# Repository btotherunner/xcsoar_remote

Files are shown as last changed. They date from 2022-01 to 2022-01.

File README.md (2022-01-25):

# xcsoar_remote
XCSoar USB RemoteControl
<br>
<br>
XCSoar Remotecontroll / Fernbedieung
<br>
#### Hardware ####
1x ALPS SKQU 4 direction Joystick w/ Switch ~ 2,73 Euro <a href="https://www.exp-tech.de/zubehoer/tasterschalter/4727/alps-skqu-4-direction-joystick-w/switch">Link zu EXPTECH</a><br>
2x Tactile Button switch (6mm) ~ 3,15 Euro (20 Stück) <a href="https://www.exp-tech.de/zubehoer/tasterschalter/6974/tactile-button-switch-6mm-x-20-pack">Link zu EXPTECH</a><br>
1x Leiterplatte ~ 30 Euro (40 Stück)  <a href="https://www.pcbway.com/">PCB Prototype the Easy Way</a><br>
1x Arduino Leonardo Board ~ (3 Stück) 25,99 Euro <a href="https://www.amazon.de/gp/product/B07FQBQ4Z6/ref=ppx_yo_dt_b_search_asin_title?ie=UTF8&psc=1">Arduino Leonardo Board</a>

<br>
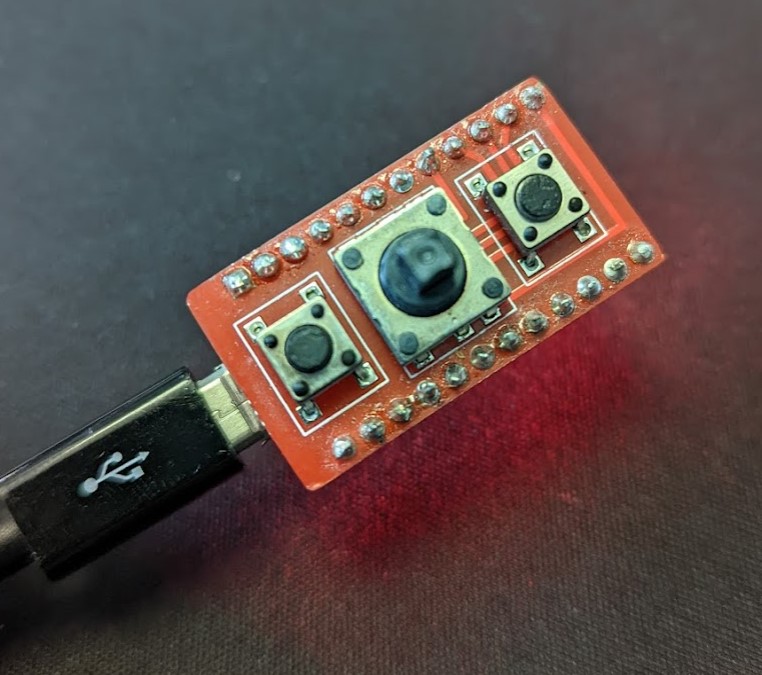
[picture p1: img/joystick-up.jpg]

<br>
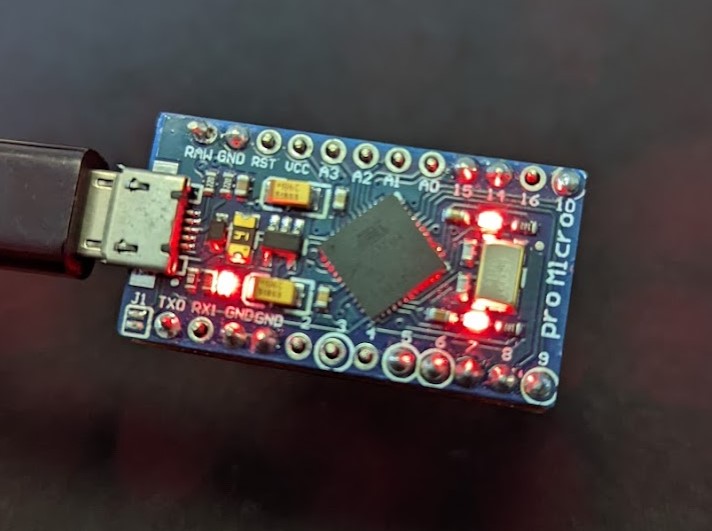
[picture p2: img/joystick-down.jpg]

<br>
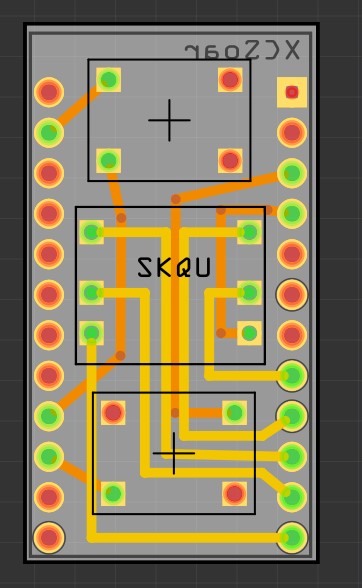
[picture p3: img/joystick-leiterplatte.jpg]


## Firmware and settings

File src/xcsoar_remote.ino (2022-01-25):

#include <Mouse.h>
#include <Keyboard.h>
#include <Button.h>
#include <ButtonEventCallback.h>
#include <PushButton.h>
#include <Bounce2.h>

// define on which pins the buttons are connected

//        Button_1_pin = N/A   // PTT switch
const int Button_2_pin = 15;    // upper LH button
const int Button_3_pin = 12;    // top button
const int Button_4_pin = 11;   // upper RH button
const int Button_5_pin = 14;   // lower RH button
const int Joy_button_pin = 6; // joystick button
const int Joy_up_pin = 9;
const int Joy_down_pin = 7;
const int Joy_left_pin = 5;
const int Joy_right_pin = 8;
const int STF_switch_pin = 4;  // STF switch 

// define press (short press) and hold (long press) functions for each button
// settings in XCSoar default.xci are
// F1 QuickMenu
// F2 Analysis
// F3 Checklist
// F4 FlarmTraffic
// F5 GotoLookup (Select Waypoint)
// F6 Setup Alternates
// F7 Setup Task
// F8 Setup Basic (wingload,bugs, QNH)
// F9
//    Status all
//    Calculator (tasks)
//
// settings in openvario.xci
// V for vario mode
// S for speed to fly mode
// M for vario menu
// Q to quit


//         Button_1 = N/A                         // PTT switch
const char Button_2_press_key = KEY_F1;           // F1 for QuickMenu
const char Button_2_hold_key = 'M';               // M for vario menu
const char Button_3_press_key = KEY_F3;           // F3 for checklist
const char Button_3_hold_key = KEY_F2;            // F2 for analysis
const char Button_4_press_key = KEY_F6;           // F6 for alternates
const char Button_4_hold_key = KEY_F5;            // F5 for waypoints
const char Button_5_press_key = KEY_ESC;          // ESC
const char Button_5_hold_key = 'Q';               // Q to quit XCSoar
const char Joy_button_press_key = KEY_RETURN;     // Enter
//         Joy_button_hold_key                    // switches between keyboard and mouse mode
const char STF_switch_on_key = 'V';               // V for vario mode when switch is on
const char STF_switch_off_key = 'S';              // S for STF mode when switch is off

// define timing for buttons etc.
const int Mouse_Move_Distance = 3;
const int joy_rebounce_interval = 3;
const int joy_key_rebounce_threshold = 20;
const int joy_key_first_pressed_threshold = 100;
const int button_hold_threshold = 500;
const int joy_hold_threshold = 1;
//const int debounce_delay = 10;                   //Debounce delay in milliseconds, not used

// define variables
boolean mouse_active = 0;
boolean first_pressed = 1;
int joy_key_counter = 0;


// Create instances of PushButtons on digital pins
PushButton STF_switch = PushButton(STF_switch_pin, ENABLE_INTERNAL_PULLUP);
PushButton Joy_up = PushButton(Joy_up_pin, ENABLE_INTERNAL_PULLUP);
PushButton Joy_down = PushButton(Joy_down_pin, ENABLE_INTERNAL_PULLUP);
PushButton Joy_left = PushButton(Joy_left_pin, ENABLE_INTERNAL_PULLUP);
PushButton Joy_right = PushButton(Joy_right_pin, ENABLE_INTERNAL_PULLUP);
PushButton Button_2 = PushButton(Button_2_pin, ENABLE_INTERNAL_PULLUP);
PushButton Button_3 = PushButton(Button_3_pin, ENABLE_INTERNAL_PULLUP);
PushButton Button_4 = PushButton(Button_4_pin, ENABLE_INTERNAL_PULLUP);
PushButton Button_5 = PushButton(Button_5_pin, ENABLE_INTERNAL_PULLUP);
PushButton Joy_button = PushButton(Joy_button_pin, ENABLE_INTERNAL_PULLUP);


void setup() {
  STF_switch.onPress(onSTF_switch);
  STF_switch.onRelease(onSTF_switch);
  
  Joy_up.onRelease(onJoyRelease);
  Joy_down.onRelease(onJoyRelease);
  Joy_left.onRelease(onJoyRelease);
  Joy_right.onRelease(onJoyRelease);

  Joy_up.onHoldRepeat(joy_hold_threshold, joy_rebounce_interval, onJoy);
  Joy_down.onHoldRepeat(joy_hold_threshold, joy_rebounce_interval, onJoy);
  Joy_left.onHoldRepeat(joy_hold_threshold, joy_rebounce_interval, onJoy);
  Joy_right.onHoldRepeat(joy_hold_threshold, joy_rebounce_interval, onJoy);
  
  Button_2.onRelease(0,button_hold_threshold-1,onButtonReleased);
  Button_3.onRelease(0,button_hold_threshold-1,onButtonReleased);
  Button_4.onRelease(0,button_hold_threshold-1,onButtonReleased);
  Button_5.onRelease(0,button_hold_threshold-1,onButtonReleased);
  Joy_button.onRelease(0,button_hold_threshold-1,onButtonReleased);
  
  Button_2.onHold(button_hold_threshold,onButtonHeld);
  Button_3.onHold(button_hold_threshold,onButtonHeld);
  Button_4.onHold(button_hold_threshold,onButtonHeld);
  Button_5.onHold(button_hold_threshold,onButtonHeld);
  Joy_button.onHold(button_hold_threshold,onButtonHeld);
 
  Keyboard.begin();
  Mouse.begin();
  joy_key_counter = 0;
}

void loop() {
  STF_switch.update();
  Button_2.update();
  Button_3.update();
  Button_4.update();
  Button_5.update();
  Joy_button.update();
  Joy_up.update();
  Joy_down.update();
  Joy_left.update();
  Joy_right.update();
}

void onButtonReleased(Button& btn){
  if(btn.is(Button_2)) Keyboard.press(Button_2_press_key);
  if(btn.is(Button_3)) Keyboard.press(Button_3_press_key);
  if(btn.is(Button_4)) Keyboard.press(Button_4_press_key);
  if(btn.is(Button_5)) Keyboard.press(Button_5_press_key);
  if(btn.is(Joy_button)) 
    if(mouse_active) Mouse.click(MOUSE_LEFT);
    else Keyboard.press(Joy_button_press_key);
  Keyboard.releaseAll();
}

void onButtonHeld(Button& btn){
  if(btn.is(Button_2)) Keyboard.press(Button_2_hold_key);
  if(btn.is(Button_3)) Keyboard.press(Button_3_hold_key);
  if(btn.is(Button_4)) Keyboard.press(Button_4_hold_key);
  if(btn.is(Button_5)) Keyboard.press(Button_5_hold_key);
  if(btn.is(Joy_button)) mouse_active = !mouse_active;
  Keyboard.releaseAll();  
} 


void onJoy(Button& btn){
  if(mouse_active && btn.isPressed()) {
    if(btn.is(Joy_up)) Mouse.move(0, -Mouse_Move_Distance);
    if(btn.is(Joy_down)) Mouse.move(0, Mouse_Move_Distance);
    if(btn.is(Joy_left)) Mouse.move(-Mouse_Move_Distance, 0);
    if(btn.is(Joy_right)) Mouse.move(Mouse_Move_Distance, 0);
  }
  if(!mouse_active && btn.isPressed() && joy_key_counter == 5) {
    if(btn.is(Joy_up)) Keyboard.press(KEY_UP_ARROW);
    if(btn.is(Joy_down)) Keyboard.press(KEY_DOWN_ARROW);
    if(btn.is(Joy_left)) Keyboard.press(KEY_LEFT_ARROW);
    if(btn.is(Joy_right)) Keyboard.press(KEY_RIGHT_ARROW);
    Keyboard.releaseAll(); 
  } 
  joy_key_counter = joy_key_counter +1; 
  if (first_pressed && joy_key_counter > joy_key_first_pressed_threshold){
    joy_key_counter = 0;
    first_pressed = 0;
  }
  if (!first_pressed && joy_key_counter > joy_key_rebounce_threshold)joy_key_counter = 0;  
}

void onJoyRelease(Button& btn){
  joy_key_counter = 0;
  first_pressed = 1;
}

void onSTF_switch(Button& btn){
  if(STF_switch.isPressed()) Keyboard.press(STF_switch_on_key);
  else
  Keyboard.press(STF_switch_off_key);
  Keyboard.releaseAll(); 
}

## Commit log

2021-06-14 Add frizing-files
    [xcsoar_remote.fzz]
2021-06-14 Add Images Case
2021-06-14 Upload 3D Case and Fusion Files
    [XCSoar_Remote v1.f3d, xcsoar_case_body.stl, xcsoar_case_deckel.stl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]
2021-06-14 Change Button Description
2021-06-14 Update Fritzing
    [xcsoar_remote.fzz]
2021-06-22 Add Button5
2021-06-25 Update FritzingFIle für Joystick
    [xcsoar_remote_joystick.fzz]
2021-06-25 Schema Anschluss - Joystick
    [xcsoar_remote_joystick.fzz]
2021-06-25 SKQU Anpassung
    [xcsoar_remote_joystick.fzz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]
2021-06-25 Update GerberFiles
    [xcsoar_remote_joystick.fzz]
2022-01-25 New Joystick Version
    [XCSoar_Remote v1.f3d, xcsoar_case_body.stl, xcsoar_case_deckel.stl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]
2022-01-25 Add Joystick Fritzing Leiterplatte
    [xcsoar_remote_joystick.fzz]
